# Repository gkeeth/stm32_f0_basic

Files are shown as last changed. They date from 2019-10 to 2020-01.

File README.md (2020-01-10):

# stm32_f0_basic
Small, bare-bones STM32F0 board

Designed for STM32F031K6. Most likely works for other MCUs as well.

Created as a test before making a bigger board. If it's useful on its own, even better.

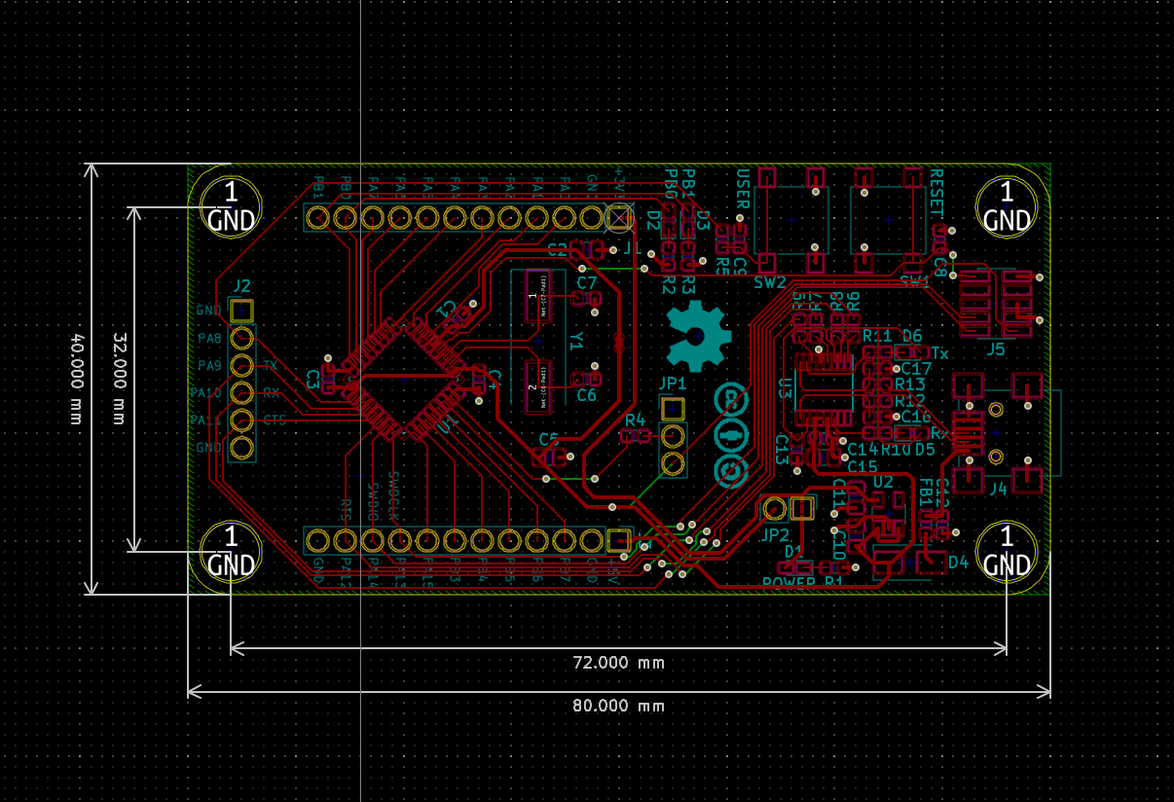
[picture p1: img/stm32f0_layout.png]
layout

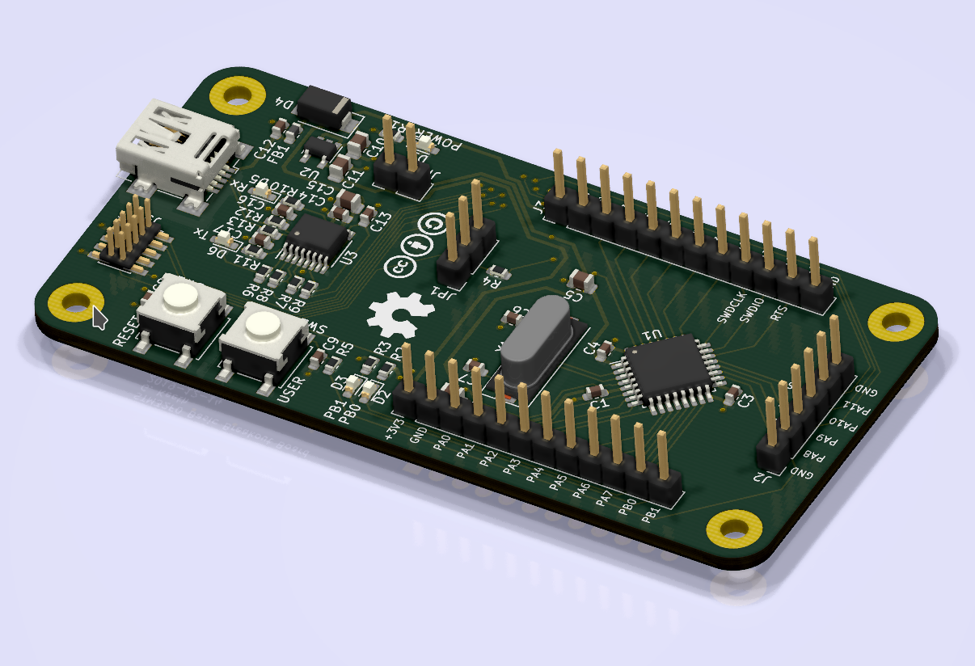
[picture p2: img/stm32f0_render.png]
render

This work is licensed under a [Creative Commons Attribution-ShareAlike 4.0
International License][cc-by-sa].

[][cc-by-sa]

[cc-by-sa]: http://creativecommons.org/licenses/by-sa/4.0/
[cc-by-sa-image]: https://licensebuttons.net/l/by-sa/4.0/88x31.png

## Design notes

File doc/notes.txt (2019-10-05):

STM32 options:

value line: STM32F030K6T6
- 32LQFP
- $1.57
access line: STM32F031K6T6
- 32LQFP
- $2.34
- adds 12-bit DAC

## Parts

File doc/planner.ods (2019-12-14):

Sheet: pinout
STM32F031K6T6
pin | pin name | alternate functions | additional functions | notes
2 | PF0-OSC_IN |  | OSC_IN
3 | PF1-OSC_OUT |  | OSC_OUT
4 | NRST |  |  | needs pushbutton and debounce capacitor (internal pullup)
5 | VDDA |  |  | needs 10nF decoupling capacitor
6 | PA0 | TIM2_CH1_ETR, USART1_CTS | ADC_IN0, RTC_TAMP2, WKUP1
7 | PA1 | TIM2_CH2, EVENTOUT, USART1_RTS | ADC_IN1
8 | PA2 | TIM2_CH3, USART1_TX | ADC_IN2
9 | PA3 | TIM2_CH4, USART1_RX | ADC_IN3
10 | PA4 | SPI1_NSS, I2S1_WS, TIM14_CH1, USART1_CK | ADC_IN4
11 | PA5 | SPI1_SCK, I2S1_CK, TIM2_CH1_ETR | ADC_IN5
12 | PA6 | SPI1_MISO, I2S1_MCK, TIM3_CH1, TIM1_BKIN, TIM16_CH1, EVENTOUT | ADC_IN6
13 | PA7 | SPI1_MOSI, I2S1_SD, TIM3_CH2, TIM14_CH1, TIM1_CH1n, TIM17_CH1, EVENTOUT | ADC_IN7
14 | PB0 | TIM3_CH3, TIM1_CH2N, EVENTOUT | ADC_IN8
15 | PB1 | TIM3_CH4, TIM14_CH1, TIM1_CH3N | ADC_IN9
16 | VSS/VSSA
17 | VDD |  |  | needs 100nF decoupling capacitor
18 | PA8 | USART1_CK, TIM1_CH1, EVENTOUT, MCO
19 | PA9 | USART1_TX, TIM1_CH2, I2C1_SCL
20 | PA10 | USART1_RX, TIM1_CH3, TIM17_BKIN, I2C1_SDA
21 | PA11 | USART1_CTS, TIM1_CH4, EVENTOUT
22 | PA12 | USART1_RTS, TIM1_ETR, EVENTOUT
23 | PA13 (SWDIO) | IR_OUT, SWDIO |  | connect to SWD connector
24 | PA14 (SWCLK) | USART1_TX, SWCLK |  | connect to SWD connector
25 | PA15 | SPI1_NSS, I2S1_WS, TIM2_CH_ETR, EVENTOUT, USART1_RX
26 | PB3 | SPI1_SCK, I2S1_CK, TIM2_CH2, EVENTOUT
27 | PB4 | SPI1_MISO, I2S1_MCK, TIM3_CH1, EVENTOUT
28 | PB5 | SPI1_MOSI, I2S1_SD, I2C1_SMBA, TIM16_BKIN, TIM3_CH2
29 | PB6 | I2C1_SCL, USART1_TX, TIM16_CH1N
30 | PB7 | I2C1_SDA, USART1_RX, TIM17_CH1N
31 | BOOT0
32 | VSS
1 | VDD |  |  | needs 100nF decoupling capacitor

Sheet: decoupling capacitors
pin number | supply | capacitor value
1 | VDD | 100nF
17 | VDD | 100nF
 | VDD | 4.7uF
5 | VDDA | 10nF
 | VDDA | 1uF

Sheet: voltage regulator
ADP121
1uF ceramic on input
1uF ceramic on output
schottky diode from 5V from USB

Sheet: USB-UART
FT230X
100k pullups on USART1_RX/TX
LEDs? Either on CBUS pins or USB pins?

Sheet: debug connector
connector pin | net
1 | VDD
2 | SWDIO
3 | GND
4 | SWDCLK
5 | GND
6 | NC
7 | NC
8 | NC
9 | GND
10 | NRST
FTSH-105-01-F-DV-K

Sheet: clock
Crystal PN | 9C-8.000MEEJ-T
load capacitance | 18.00 | pF
stray capacitance | 5.00 | pF
capacitor values | 26 | pF
series resistor (necessary?) | 765.17 | R

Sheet: additional circuits
description | STM32 connection | part number | notes
user LED0 | PB0 |  | Green, 330R resistor
user LED1 | PB1 |  | Blue, 660R resistor
power LED | 3V3 |  | Red, 1k resistor. Put upstream of IDD jumper
reset button | nRST |  | debounced with 100nF. Pulled up internally
user button | PA8 |  | debounced with 100nF. Pulled up internally. Connected with 0R jumper.
IDD jumper | 3V3 to VDD
BOOT0 | BOOT0 |  | 10k pull to jumpers for GND/VDD (normally GND for flash boot)
USB connector |  |  | 5V from usb power
USB-UART converter |  |  | USART1_RX/TX have 100k pullups on them, PA9-12 connected to converter via 0R resistors, use FT230X

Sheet: software notes
Treat PB2 and PB8 as unconnected pins (do I need to set them to a specific level in software?)

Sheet: external headers
Header | Header Pin | pin | pin name
left | 1 |  | 3V3
left | 2 |  | GND
left | 3 | 6 | PA0
left | 4 | 7 | PA1
left | 5 | 8 | PA2
left | 6 | 9 | PA3
left | 7 | 10 | PA4
left | 8 | 11 | PA5
left | 9 | 12 | PA6
left | 10 | 13 | PA7
left | 11 | 14 | PB0
left | 12 | 15 | PB1
right | 1 |  | 3V3
right | 2 |  | GND
right | 3 | 30 | PB7
right | 4 | 29 | PB6
right | 5 | 28 | PB5
right | 6 | 27 | PB4
right | 7 | 26 | PB3
right | 8 | 25 | PA15
right | 9 | 24 | PA14 (SWCLK)
right | 10 | 23 | PA13 (SWDIO)
right | 11 | 22 | PA12
right | 12 |  | GND
bottom | 1 |  | GND | ?
bottom | 2 | 18 | PA8
bottom | 3 | 19 | PA9
bottom | 4 | 20 | PA10
bottom | 5 | 21 | PA11
bottom | 6 |  | GND
 |  |  |  |  | ?

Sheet: example
pin | pin name | alternate functions | additional functions | selected function | selected function
6 | PA0 | TIM2_CH1_ETR, USART1_CTS | ADC_IN0, RTC_TAMP2, WKUP1
7 | PA1 | TIM2_CH2, EVENTOUT, USART1_RTS | ADC_IN1
8 | PA2 | TIM2_CH3, USART1_TX | ADC_IN2 | USART1_TX
9 | PA3 | TIM2_CH4, USART1_RX | ADC_IN3 | USART1_RX
10 | PA4 | SPI1_NSS, I2S1_WS, TIM14_CH1, USART1_CK | ADC_IN4
11 | PA5 | SPI1_SCK, I2S1_CK, TIM2_CH1_ETR | ADC_IN5
12 | PA6 | SPI1_MISO, I2S1_MCK, TIM3_CH1, TIM1_BKIN, TIM16_CH1, EVENTOUT | ADC_IN6
13 | PA7 | SPI1_MOSI, I2S1_SD, TIM3_CH2, TIM14_CH1, TIM1_CH1n, TIM17_CH1, EVENTOUT | ADC_IN7
14 | PB0 | TIM3_CH3, TIM1_CH2N, EVENTOUT | ADC_IN8 | user button | LED0
15 | PB1 | TIM3_CH4, TIM14_CH1, TIM1_CH3N | ADC_IN9 |  | LED1
18 | PA8 | USART1_CK, TIM1_CH1, EVENTOUT, MCO |  | USART1_CK | user button
19 | PA9 | USART1_TX, TIM1_CH2, I2C1_SCL |  | I2C1_SCL | USART1_TX
20 | PA10 | USART1_RX, TIM1_CH3, TIM17_BKIN, I2C1_SDA |  | I2C1_SDA | USART1_RX
21 | PA11 | USART1_CTS, TIM1_CH4, EVENTOUT |  | USART1_CTS | USART1_CTS
22 | PA12 | USART1_RTS, TIM1_ETR, EVENTOUT |  | USART1_RTS | USART1_RTS
23 | PA13 (SWDIO) | IR_OUT, SWDIO |  | SWDIO | SWDIO
24 | PA14 (SWCLK) | USART1_TX, SWCLK |  | SWCLK | SWCLK
25 | PA15 | SPI1_NSS, I2S1_WS, TIM2_CH_ETR, EVENTOUT, USART1_RX |  | SPI1_NSS | SPI1_NSS
26 | PB3 | SPI1_SCK, I2S1_CK, TIM2_CH2, EVENTOUT |  | SPI1_SCK | SPI1_SCK
27 | PB4 | SPI1_MISO, I2S1_MCK, TIM3_CH1, EVENTOUT |  | SPI1_MISO | SPI1_MISO
28 | PB5 | SPI1_MOSI, I2S1_SD, I2C1_SMBA, TIM16_BKIN, TIM3_CH2 |  | SPI1_MOSI | SPI1_MOSI
29 | PB6 | I2C1_SCL, USART1_TX, TIM16_CH1N |  | LED0 | I2C1_SCL
30 | PB7 | I2C1_SDA, USART1_RX, TIM17_CH1N |  | LED1 | I2C1_SDA

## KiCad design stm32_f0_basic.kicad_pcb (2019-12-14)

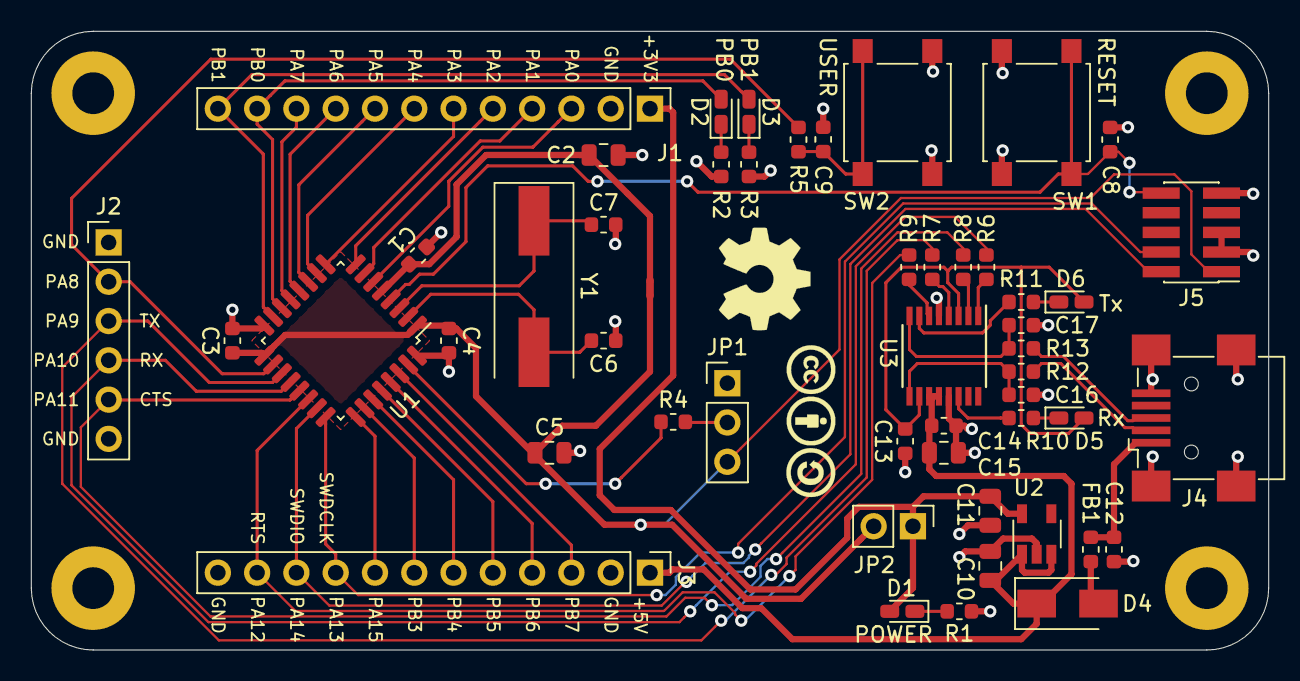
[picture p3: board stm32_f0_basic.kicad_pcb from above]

Board: 2 copper layers, 80.0 x 40.0 mm, 58 parts (1 on the bottom side), 52 nets.

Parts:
C1, C12: 10n; C_0603_1608Metric
C2, C10, C11: 1u; C_0805_2012Metric
C3, C4, C8, C9, C13, C14: 100n; C_0603_1608Metric
C5, C15: 4.7u; C_0805_2012Metric
C6, C7: 27p; C_0603_1608Metric
C16, C17: 47pF; C_0603_1608Metric
D1: red; LED_0603_1608Metric_Castellated
D2: green; LED_0603_1608Metric_Castellated
D3: blue; LED_0603_1608Metric_Castellated
D4: B140-E3; D_SMA
D5: RX (green); LED_0603_1608Metric_Castellated
D6: TX (red); LED_0603_1608Metric_Castellated
FB1: Ferrite_Bead; L_0603_1608Metric
H1, H2, H3, H4: MountingHole_Pad; MountingHole_2.7mm_M2.5_Pad
J1, J3: Conn_01x12_Male; PinHeader_1x12_P2.54mm_Vertical
J2: Conn_01x06_Male; PinHeader_1x06_P2.54mm_Vertical
J4: USB_B_Mini; USB_Mini-B_Wuerth_65100516121_Horizontal
J5: Conn_ARM_JTAG_SWD_10; PinHeader_2x05_P1.27mm_Vertical_SMD
JP1: Jumper_3_Bridged12; PinHeader_1x03_P2.54mm_Vertical
JP2: Jumper_2_Bridged; PinHeader_1x02_P2.54mm_Vertical
LOGO1: Logo_Open_Hardware_Small; OSHW-Symbol_6.7x6mm_SilkScreen
LOGO2: CC-BY-SA_0.33in; CC-BY-SA_SilkScreenTop_Small
LOGO3: Logo_MadeWithKiCad; KiCad-Logo2_5mm_SilkScreen
NT1: Net-Tie_2; NetTie-2_SMD_Pad0.5mm
R1: 1k; R_0603_1608Metric
R2, R10, R11: 330; R_0603_1608Metric
R3: 660; R_0603_1608Metric
R4: 10k; R_0603_1608Metric
R5, R6, R7, R8, R9: 0; R_0603_1608Metric
R12, R13: 27; R_0603_1608Metric
SW1, SW2: B3S-1000P; SW_SPST_B3S-1000
U1: STM32F031K6Tx; LQFP-32_7x7mm_P0.8mm
U2: ADP121-AUJZ33R7; TSOT-23-5
U3: FT230XS; SSOP-16_3.9x4.9mm_P0.635mm
Y1: 8MHz; Crystal_SMD_HC49-SD

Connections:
+3V3: C11.1, D1.2, J1.1, JP2.1, U2.5
+5V: C10.1, C14.2, C15.1, D4.1, J3.1, U2.1, U2.3, U3.11, U3.12
/stm32f0/BOOT0: R4.1, U1.31
/stm32f0/NRST: C8.1, J5.10, SW1.2, U1.4
/stm32f0/PA0: J1.3, U1.6
/stm32f0/PA1: J1.4, U1.7
/stm32f0/PA2: J1.5, U1.8
/stm32f0/PA3: J1.6, U1.9
/stm32f0/PA4: J1.7, U1.10
/stm32f0/PA5: J1.8, U1.11
/stm32f0/PA6: J1.9, U1.12
/stm32f0/PA7: J1.10, U1.13
/stm32f0/PA8: J2.2, R5.2, U1.18
/stm32f0/PA9_USART1_TX: J2.3, R7.2, U1.19
/stm32f0/PA10_USART1_RX: J2.4, R6.2, U1.20
/stm32f0/PA11_USART1_CTS: J2.5, R8.2, U1.21
/stm32f0/PA12_USART1_RTS: J3.11, R9.2, U1.22
/stm32f0/PA13_SWDIO: J3.10, J5.2, U1.23
/stm32f0/PA14_SWDCLK: J3.9, J5.4, U1.24
/stm32f0/PA15: J3.8, U1.25
/stm32f0/PB0: D2.2, J1.11, U1.14
/stm32f0/PB1: D3.2, J1.12, U1.15
/stm32f0/PB3: J3.7, U1.26
/stm32f0/PB4: J3.6, U1.27
/stm32f0/PB5: J3.5, U1.28
/stm32f0/PB6: J3.4, U1.29
/stm32f0/PB7: J3.3, U1.30
/usb_uart/UART_CTS: R9.1, U3.6
/usb_uart/UART_RTS: R8.1, U3.2
/usb_uart/UART_RXD: R7.1, U3.4
/usb_uart/UART_TXD: R6.1, U3.1
/usb_uart/USBUART+: C17.1, R13.1, U3.8
/usb_uart/USBUART-: C16.1, R12.1, U3.9
/usb_uart/USB_D+: J4.3, R13.2
/usb_uart/USB_D-: J4.2, R12.2
GND: C1.2, C2.2, C3.2, C4.2, C5.2, C6.2, C7.2, C8.2, C9.2, C10.2, C11.2, C12.1, C13.1, C14.1, C15.2, C16.2, C17.2, H1.1, H2.1, H3.1, H4.1, J1.2, J2.1, J2.6, J3.2, J3.12, J4.5, J4.6, J5.3, J5.5, J5.9, JP1.1, R1.1, R2.1, R3.1, SW1.1, SW2.1, U1.16, U1.32, U2.2, U3.5, U3.13
unnamed: C6.1, U1.2, Y1.2
unnamed: C7.1, U1.3, Y1.1
unnamed: C9.1, R5.1, SW2.2
unnamed: C12.2, FB1.2, J4.1
unnamed: C13.2, D5.2, D6.2, U3.3, U3.10
unnamed: D1.1, R1.2
unnamed: D2.1, R2.2
unnamed: D3.1, R3.2
unnamed: D4.2, FB1.1
unnamed: D5.1, R10.2
unnamed: D6.1, R11.2
unnamed: JP1.2, R4.2
unnamed: R10.1, U3.14
unnamed: R11.1, U3.7
VDD: C3.1, C4.1, C5.1, J5.1, JP1.3, JP2.2, NT1.1, U1.1, U1.17
VDDA: C1.1, C2.1, NT1.2, U1.5

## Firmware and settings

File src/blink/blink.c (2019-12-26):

// example based on libopencm3 miniblink/systick_blink/button examples

#include <libopencm3/stm32/rcc.h>
#include <libopencm3/stm32/gpio.h>
#include <libopencm3/stm32/usart.h>
#include <libopencm3/cm3/nvic.h>
#include <libopencm3/cm3/systick.h>

// LEDs are on PB0 and PB1
#define PORT_LED GPIOB
#define PIN_LED0 GPIO0
#define PIN_LED1 GPIO1

volatile uint32_t counter = 0;

void sys_tick_handler(void) {
    ++counter;
}

uint32_t millis(void);
uint32_t millis(void) {
    return counter;
}

static void setup(void) {
    // use external 8MHz crystal to derive 48MHz clock from PLL
    rcc_clock_setup_in_hse_8mhz_out_48mhz();
    STK_CVR = 0; // clear systick current value to start immediately

    // every 1 ms (1000 Hz)
    systick_set_frequency(1000, rcc_ahb_frequency);
    systick_counter_enable();
    systick_interrupt_enable();

    // setup LED pins
    rcc_periph_clock_enable(RCC_GPIOB);
    // set LED pins to output push-pull
    gpio_mode_setup(PORT_LED, GPIO_MODE_OUTPUT, GPIO_PUPD_NONE, PIN_LED0 | PIN_LED1);

    // setup button pin
    rcc_periph_clock_enable(RCC_GPIOA);
    gpio_mode_setup(GPIOA, GPIO_MODE_INPUT, GPIO_PUPD_PULLUP, GPIO8);

    // setup PA0, PA1, PA2 to show which blink speed is set
    gpio_mode_setup(GPIOA, GPIO_MODE_OUTPUT, GPIO_PUPD_NONE, GPIO0 | GPIO1 | GPIO2);

    // set PA8 to AF0 for MCO (main clock out)
    // NOTE: this will not work on stm32f0_basic board because PA8 is
    // tied to the user button and therefore has a debounce capacitor hanging
    // off of it. A jumper can be removed to disconnect the button/capacitor if
    // desired.
    /*
    rcc_periph_clock_enable(RCC_GPIOA);
    gpio_mode_setup(GPIOA, GPIO_MODE_AF, GPIO_PUPD_NONE, GPIO8);
    gpio_set_af(GPIOA, 0, GPIO8);
    rcc_set_mco(RCC_CFGR_MCO_SYSCLK);
    */

    // setup USART1
    gpio_mode_setup(GPIOA, GPIO_MODE_AF, GPIO_PUPD_NONE, GPIO9 | GPIO10);
    gpio_set_af(GPIOA, GPIO_AF1, GPIO9 | GPIO10);
    rcc_periph_clock_enable(RCC_USART1);
    usart_set_baudrate(USART1, 115200);
    usart_set_databits(USART1, 8);
    usart_set_parity(USART1, USART_PARITY_NONE);
    usart_set_stopbits(USART1, USART_CR2_STOPBITS_1);
    usart_set_mode(USART1, USART_MODE_TX_RX);
    usart_set_flow_control(USART1, USART_FLOWCONTROL_NONE);
    usart_enable(USART1);
}



int main(void) {
    int i = 0;
    int button_armed = 0;
    uint32_t blink_delays[] = {100, 500, 1000};
    uint32_t last_flash_millis;

    setup();
    last_flash_millis = millis();

    while(1) {
        int button_pressed = !gpio_get(GPIOA, GPIO8);
        if (button_pressed && button_armed) {
            // disarm button (until button is released)
            button_armed = 0;

            // make LED blink faster
            i = (i + 1) % 3;

            // PA{0-2} high to represent blink speed
            gpio_clear(GPIOA, GPIO0 | GPIO1 | GPIO2);
            switch (i) {
                case 0:
                    gpio_set(GPIOA, GPIO0);
                    break;
                case 1:
                    gpio_set(GPIOA, GPIO1);
                    break;
                case 2:
                    gpio_set(GPIOA, GPIO2);
                    break;
            }
            // send current state over usart1
            usart_send_blocking(USART1, (char) (i + 48));
            usart_send_blocking(USART1, '\r');
            usart_send_blocking(USART1, '\n');
        } else if (!button_pressed) {
            button_armed = 1;
        }


        if ((millis() - last_flash_millis) > blink_delays[i]) {
            gpio_toggle(PORT_LED, PIN_LED0);
            gpio_toggle(PORT_LED, PIN_LED1);
            last_flash_millis = millis();
        }

        // echo any input over USART1
        if (usart_get_flag(USART1, USART_ISR_RXNE)) {
            // there's a byte to be received
            char c = usart_recv_blocking(USART1);
            // echo it back
            usart_send_blocking(USART1, c);
            if (c == '\r') {
                usart_send_blocking(USART1, '\n');
            }
        }
    }

    return 0;
}

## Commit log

2019-10-05 add possible STM32 parts to notes
2019-10-07 add initial schematic
    [planner.ods, stm32_f0_basic.kicad_pcb, stm32_f0_basic.sch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]
2019-10-07 update FTDI decoupling, add ferrite to VBUS, add mounting holes
    [stm32_f0_basic.sch, stm32f0.sch, usb_uart.sch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]
2019-10-14 complete initial layout
    * components placed
    * all nets routed
    * switches, LEDs, connectors labeled
    * TODO: route USB DM/DP as a diff pair?
    * TODO: add 3D models for USB connector, pushbutton switches
    [stm32_f0_basic.kicad_pcb, stm32_f0_basic.sch, usb_uart.sch]
2019-10-17 rearrange headers and update silk labels (in progress)
    [stm32_f0_basic.kicad_pcb]
2019-10-17 Update USB schematic, redo lots of routing
    * add series resistors and shunt capacitors to usb diff pair
    * place usb-uart IC optimally for connecting to usb connector
    * move bypass caps and resistors attached to usb-uart
    * move user & reset buttons next to each other
    * move user LEDs close to buttons
    * move bottom connector
    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
    [stm32_f0_basic.kicad_pcb, usb_uart.sch]
2019-10-17 Route USB traces
    * rename USB traces in schematic so they can be routed as a differential
    pair
    * route USB traces
    * note: USB traces are routed as a differential pair, but not as a
    transmission line of the correct 90R differential impedance, because
    it's not feasible on a 2-layer, 1.6mm board (traces would be huge).
    Doesn't matter for this short of a distance.
    [stm32_f0_basic.kicad_pcb, stm32_f0_basic.sch, usb_uart.sch]
2019-10-19 adjust traces and update TODO (3D models done)
    [stm32_f0_basic.kicad_pcb]
2019-10-21 add Creative Commons/OSHW/Kicad/project info silkscreen
    [stm32_f0_basic.kicad_pcb, stm32_f0_basic.sch]
2019-12-14 minor planner updates
    [planner.ods]
2019-12-14 adjust ground plane, add pin silk reference
    [stm32_f0_basic.kicad_pcb]
2019-12-14 generate gerbers for r0 production
    [stm32_f0_basic-B_Cu.gbr, stm32_f0_basic-B_Mask.gbr, stm32_f0_basic-B_SilkS.gbr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]
2019-12-14 add board images to README
2019-12-22 add bom info
    [stm32_f0_basic.sch, stm32f0.sch, usb_uart.sch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]
2019-12-24 add basic blink example source code
    [stm32f0_basic.cfg]
2019-12-24 add button functionality to blink example
2019-12-26 Add several features to blink
    - added UART functionality:
    - echo any received bytes back
    - transmit blink delay whenever button is pressed (NOTE: continues
    to transmit as long as button is pressed; algorithm needs to change)
    - GPIOs PA0-2 now are asserted to indicate mode
2019-12-26 improve algorithm so blink speed changes only once per button press
2020-01-10 add STM32 part number to readme

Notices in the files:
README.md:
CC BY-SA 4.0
